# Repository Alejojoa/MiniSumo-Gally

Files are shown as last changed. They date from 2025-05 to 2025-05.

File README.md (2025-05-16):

# MiniSumo "Gally"                   
Mini sumo diseñado para competir en la LNR. 
Este repositorio contiene todas las piezas fabricables del Robot, y extras como soportes, versiones no finales del chasis, otros diseños de chasis, etc.

## ⚙️ Características 

- Tamaño: [10x10]
- Peso: [470g]
- Controlador: [Arduino Nano]
- Sensores:
  - Sensores de línea infrarrojos QRE-1113 x 2
  - Sensores JS40F x 4
- Motores: [Motores JSUMO CORE 400RPM]
- Batería: [Tattu 3S 450mAh]

# Pre Render del chasis final del robot.



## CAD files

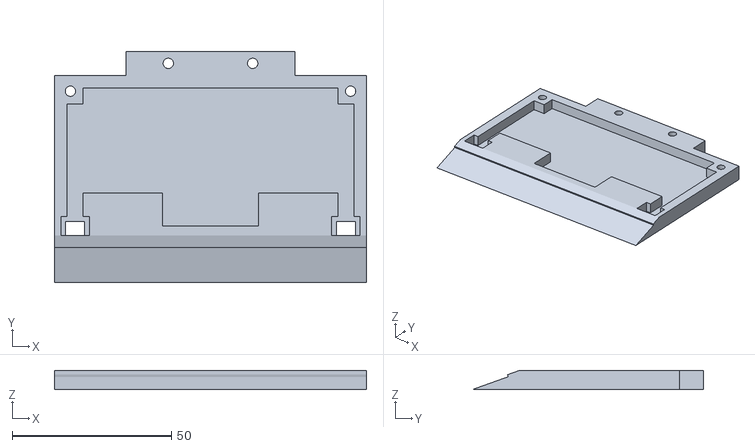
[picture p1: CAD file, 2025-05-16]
Hardware 3D (Chasis)/BasePLA.stl
98.0 x 72.6 x 6.00

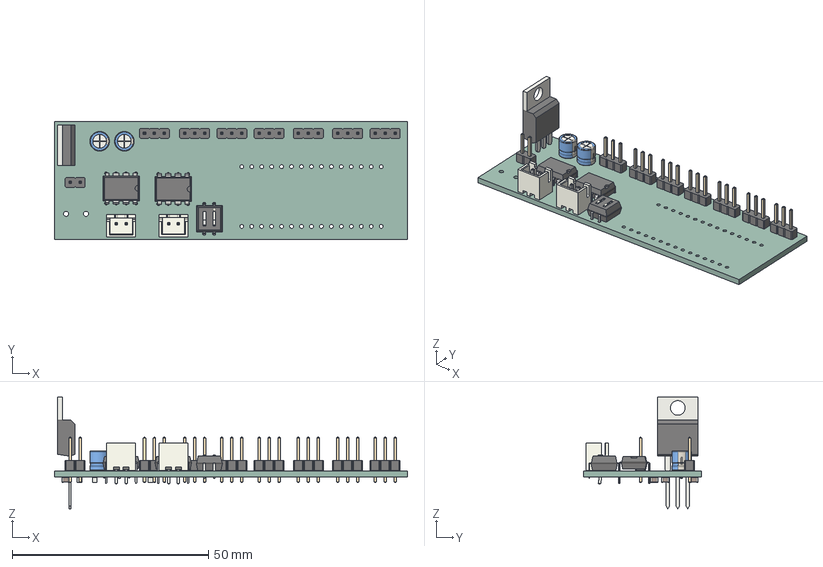
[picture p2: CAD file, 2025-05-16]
Hardware/UntestedBoard/Minisumo NANO.step
90.0 x 30.0 x 28.5 mm
SW_DIP_SPSTx02_Slide_67x664mm_W762mm_P254mm_LowProfile
PinHeader_1x02_P254mm_Vertical
JST_B2B_XH_A x 2
TO-220-3_Vertical
PinHeader_1x03_P254mm_Vertical x 7
CP_Radial_D50mm_P250mm x 2
DIP-8_W7.62mm x 2
C_0805_2012Metric x 4
Minisumo NANO_PCB

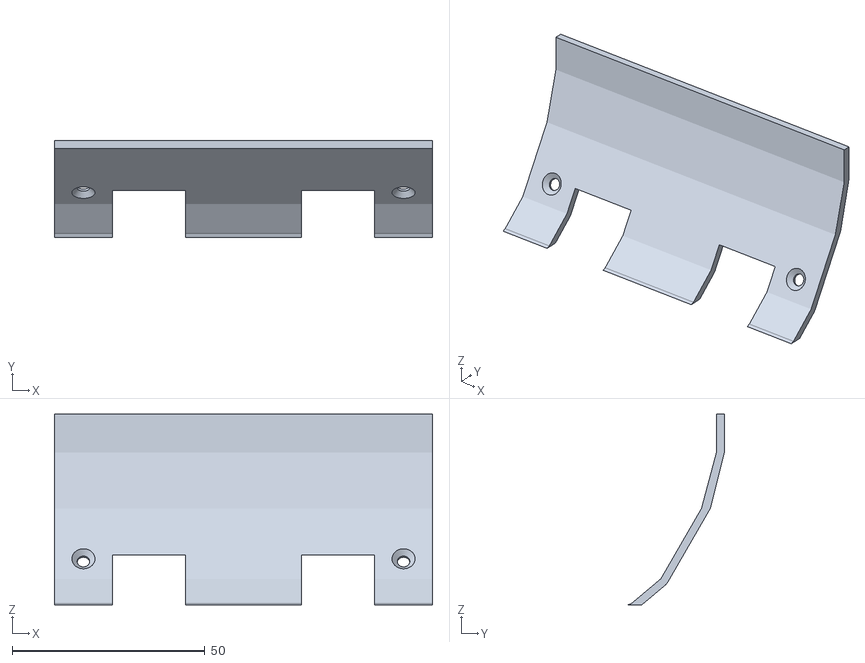
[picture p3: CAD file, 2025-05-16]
Hardware 3D (Chasis)/Frente.stl
98.0 x 25.1 x 49.5

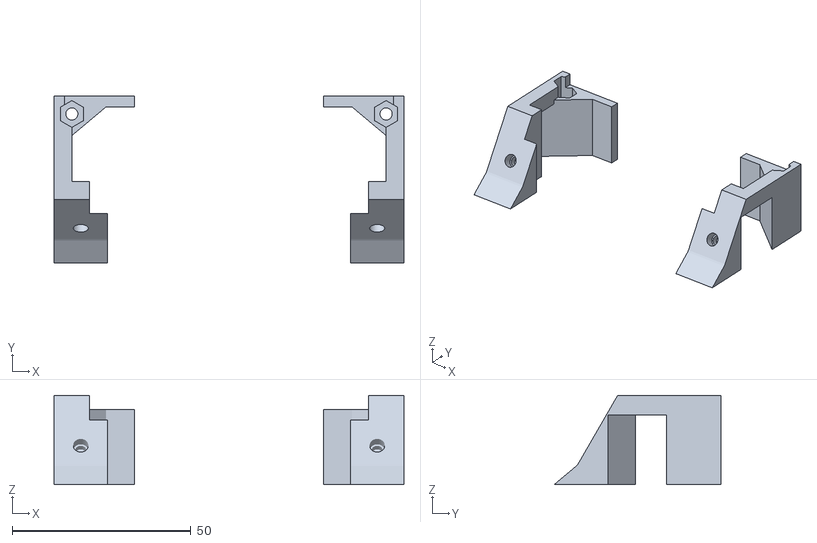
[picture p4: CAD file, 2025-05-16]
Hardware 3D (Chasis)/Laterales.stl
98.0 x 46.7 x 25.0

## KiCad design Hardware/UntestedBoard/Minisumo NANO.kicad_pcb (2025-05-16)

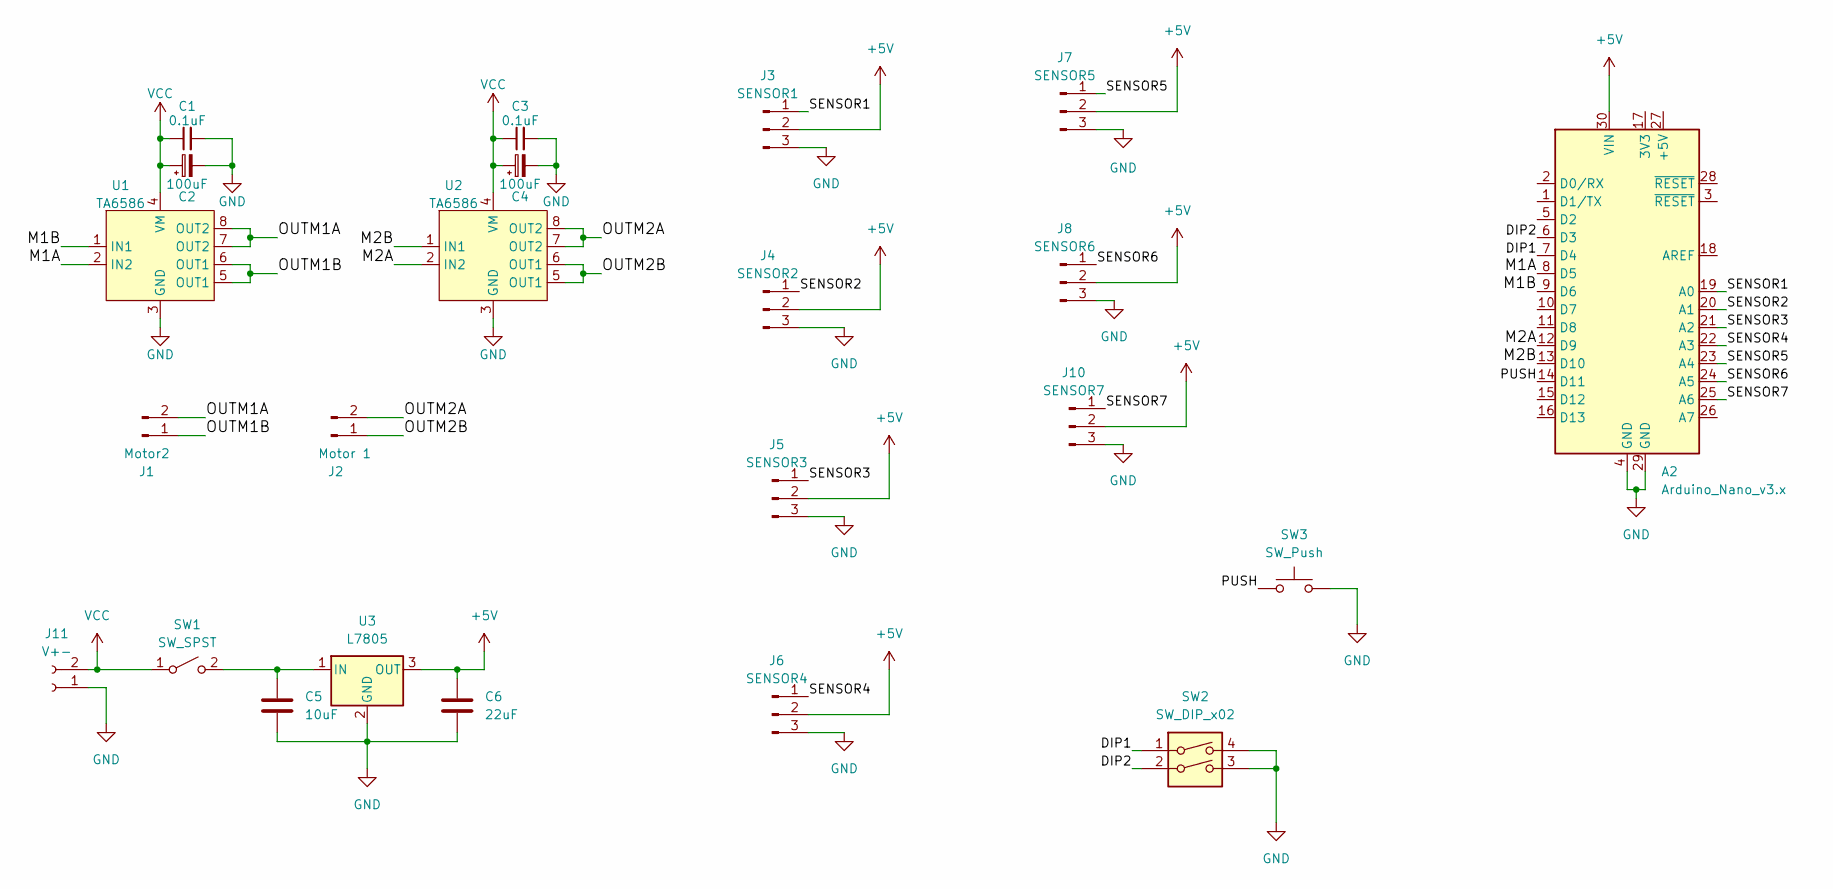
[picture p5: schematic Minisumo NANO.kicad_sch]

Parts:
A2: Arduino_Nano_v3.x; Arduino_Nano
C1, C3: 0.1uF; C_0805_2012Metric_Pad1.18x1.45mm_HandSolder
C2, C4: 100uF; CP_Radial_D5.0mm_P2.50mm
C5: 10uF; C_0805_2012Metric_Pad1.18x1.45mm_HandSolder
C6: 22uF; C_0805_2012Metric_Pad1.18x1.45mm_HandSolder
J1: Motor2; JST_XH_B2B-XH-A_1x02_P2.50mm_Vertical
J2: Motor 1; JST_XH_B2B-XH-A_1x02_P2.50mm_Vertical
J3: SENSOR1; PinHeader_1x03_P2.54mm_Vertical
J4: SENSOR2; PinHeader_1x03_P2.54mm_Vertical
J5: SENSOR3; PinHeader_1x03_P2.54mm_Vertical
J6: SENSOR4; PinHeader_1x03_P2.54mm_Vertical
J7: SENSOR5; PinHeader_1x03_P2.54mm_Vertical
J8: SENSOR6; PinHeader_1x03_P2.54mm_Vertical
J10: SENSOR7; PinHeader_1x03_P2.54mm_Vertical
J11: V+-; BORNERA2
SW1: SW_SPST; PinHeader_1x02_P2.54mm_Vertical
SW2: SW_DIP_x02; SW_DIP_SPSTx02_Slide_6.7x6.64mm_W7.62mm_P2.54mm_LowProfile
SW3: SW_Push; SW_PUSH_6mm_H5mm
U1, U2: TA6586; DIP-8_W7.62mm
U3: L7805; TO-220-3_Vertical

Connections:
+5V: A2.30 (VIN), C6.1, J3.2, J4.2, J5.2, J6.2, J7.2, J8.2, J10.2, U3.3 (OUT)
/DIP1: A2.7 (D4), SW2.1
/DIP2: A2.6 (D3), SW2.2
/M1A: A2.8 (D5), U1.2 (IN2)
/M1B: A2.9 (D6), U1.1 (IN1)
/M2A: A2.12 (D9), U2.2 (IN2)
/M2B: A2.13 (D10), U2.1 (IN1)
/OUTM1A: J1.2, U1.7 (OUT2), U1.8 (OUT2)
/OUTM1B: J1.1, U1.5 (OUT1), U1.6 (OUT1)
/OUTM2A: J2.2, U2.7 (OUT2), U2.8 (OUT2)
/OUTM2B: J2.1, U2.5 (OUT1), U2.6 (OUT1)
/PUSH: A2.14 (D11), SW3.1
/SENSOR1: A2.19 (A0), J3.1
/SENSOR2: A2.20 (A1), J4.1
/SENSOR3: A2.21 (A2), J5.1
/SENSOR4: A2.22 (A3), J6.1
/SENSOR5: A2.23 (A4), J7.1
/SENSOR6: A2.24 (A5), J8.1
/SENSOR7: A2.25 (A6), J10.1
GND: A2.4 (GND), A2.29 (GND), C1.2, C2.2, C3.2, C4.2, C5.2, C6.2, J3.3, J4.3, J5.3, J6.3, J7.3, J8.3, J10.3, J11.1, SW2.3, SW2.4, SW3.2, U1.3 (GND), U2.3 (GND), U3.2 (GND)
unnamed: C5.1, SW1.2 (B), U3.1 (IN)
VCC: C1.1, C2.1, C3.1, C4.1, J11.2, SW1.1 (A), U1.4 (VM), U2.4 (VM)

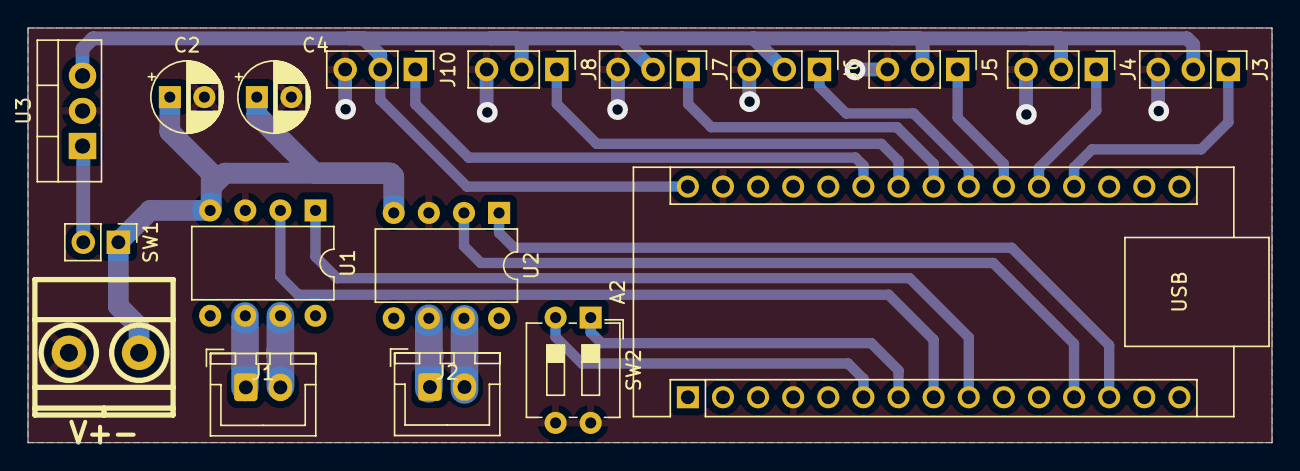
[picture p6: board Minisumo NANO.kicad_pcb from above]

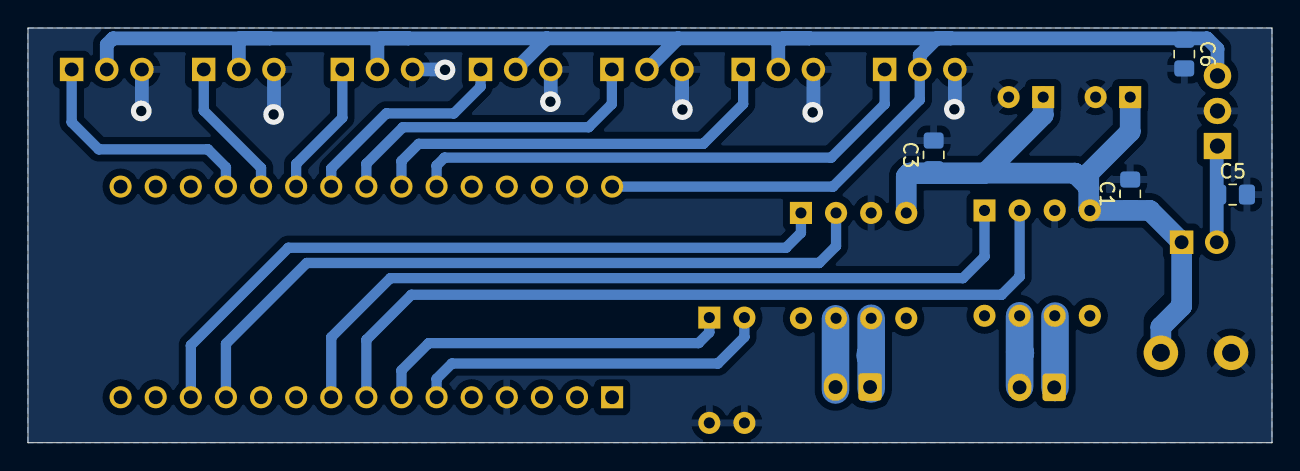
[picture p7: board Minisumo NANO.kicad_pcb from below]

Board: 2 copper layers, 90.0 x 30.0 mm, 22 parts (4 on the bottom side), 21 nets.

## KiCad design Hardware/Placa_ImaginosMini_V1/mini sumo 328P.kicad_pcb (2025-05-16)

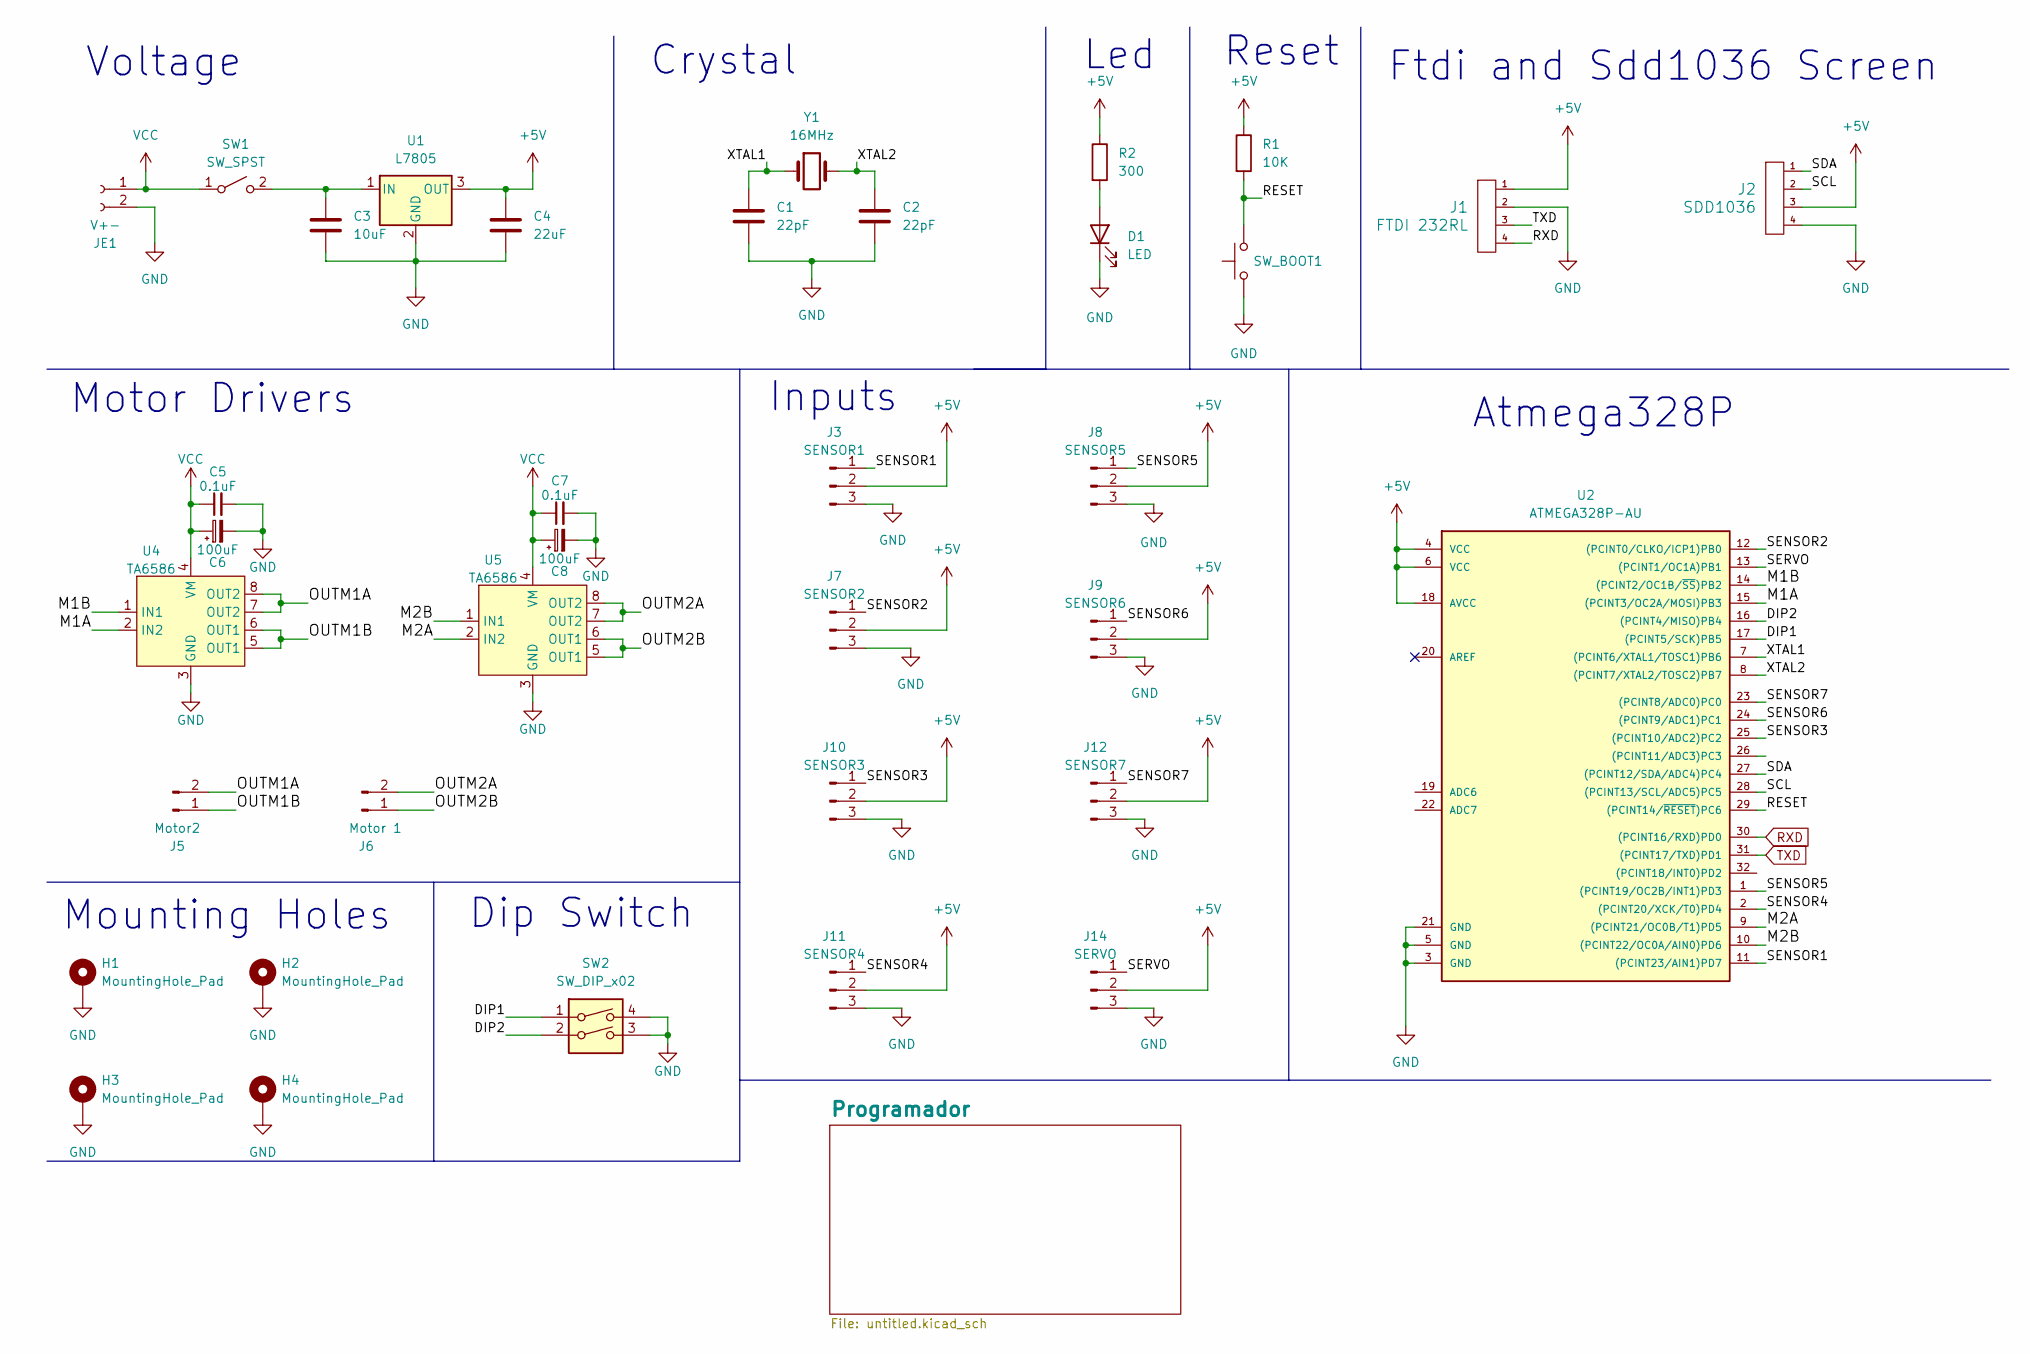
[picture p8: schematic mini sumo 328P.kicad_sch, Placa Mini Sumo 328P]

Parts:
C1, C2: 22pF; C_0805_2012Metric_Pad1.18x1.45mm_HandSolder
C3: 10uF; C_0805_2012Metric_Pad1.18x1.45mm_HandSolder
C4: 22uF; C_0805_2012Metric_Pad1.18x1.45mm_HandSolder
C5, C7: 0.1uF; C_0805_2012Metric_Pad1.18x1.45mm_HandSolder
C6, C8: 100uF; CP_EIA-3216-18_Kemet-A_Pad1.58x1.35mm_HandSolder
D1: LED; LED_0805_2012Metric_Pad1.15x1.40mm_HandSolder
H1, H2, H3, H4: MountingHole_Pad; MountingHole_3.2mm_M3_Pad_Via
J1: FTDI 232RL; PinHeader_1x04_P2.54mm_Vertical
J2: SDD1036; PinSocket_1x04_P2.54mm_Vertical
J3: SENSOR1; Smd pad vias x3
J5: Motor2; JST_XH_B2B-XH-A_1x02_P2.50mm_Vertical
J6: Motor 1; JST_XH_B2B-XH-A_1x02_P2.50mm_Vertical
J7: SENSOR2; Smd pad vias x3
J8: SENSOR5; Smd pad vias x3
J9: SENSOR6; Smd pad vias x3
J10: SENSOR3; Smd pad vias x3
J11: SENSOR4; Smd pad vias x3
J12: SENSOR7; Smd pad vias x3
J14: SERVO; PinSocket_1x03_P2.54mm_Vertical
JE1: V+-; BORNERA2_DUO
R1: 10K; R_0805_2012Metric_Pad1.20x1.40mm_HandSolder
R2: 300; R_0805_2012Metric_Pad1.20x1.40mm_HandSolder
SW1: SW_SPST; PinHeader_1x02_P2.54mm_Vertical
SW2: SW_DIP_x02; SW_DIP_SPSTx02_Slide_6.7x6.64mm_W7.62mm_P2.54mm_LowProfile
SW_BOOT1: SW_Push; Pulsador_SMD_2_BAJO
U1: L7805; TO-252-2
U2: ATMEGA328P-AU; TQFP-32_7x7mm_Pitch0.8mm
U4, U5: TA6586; DIP-8_W7.62mm
Y1: 16MHz; Crystal_HC49-4H_Vertical

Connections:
+5V: C4.1, J1.1, J2.3, J3.2, J7.2, J8.2, J9.2, J10.2, J11.2, J12.2, J14.2, R1.1, R2.1, U1.3 (OUT), U2.4 (VCC), U2.6 (VCC), U2.18 (AVCC); also elsewhere on the board
/DIP1: SW2.1, U2.17 ((PCINT5/SCK)PB5)
/DIP2: SW2.2, U2.16 ((PCINT4/MISO)PB4)
/M1A: U2.15 ((PCINT3/OC2A/MOSI)PB3), U4.2 (IN2)
/M1B: U2.14 ((PCINT2/OC1B/~SS)PB2), U4.1 (IN1)
/M2A: U2.9 ((PCINT21/OC0B/T1)PD5), U5.2 (IN2)
/M2B: U2.10 ((PCINT22/OC0A/AIN0)PD6), U5.1 (IN1)
/OUTM1A: J5.2, U4.7 (OUT2), U4.8 (OUT2)
/OUTM1B: J5.1, U4.5 (OUT1), U4.6 (OUT1)
/OUTM2A: J6.2, U5.7 (OUT2), U5.8 (OUT2)
/OUTM2B: J6.1, U5.5 (OUT1), U5.6 (OUT1)
/RESET: R1.2, SW_BOOT1.2, U2.29 ((PCINT14/~RESET)PC6)
/SCL: J2.2, U2.28 ((PCINT13/SCL/ADC5)PC5)
/SDA: J2.1, U2.27 ((PCINT12/SDA/ADC4)PC4)
/SENSOR1: J3.1, U2.11 ((PCINT23/AIN1)PD7)
/SENSOR2: J7.1, U2.12 ((PCINT0/CLKO/ICP1)PB0)
/SENSOR3: J10.1, U2.25 ((PCINT10/ADC2)PC2)
/SENSOR4: J11.1, U2.2 ((PCINT20/XCK/T0)PD4)
/SENSOR5: J8.1, U2.1 ((PCINT19/OC2B/INT1)PD3)
/SENSOR6: J9.1, U2.24 ((PCINT9/ADC1)PC1)
/SENSOR7: J12.1, U2.23 ((PCINT8/ADC0)PC0)
/SERVO: J14.1, U2.13 ((PCINT1/OC1A)PB1)
/XTAL1: C1.1, U2.7 ((PCINT6/XTAL1/TOSC1)PB6), Y1.1
/XTAL2: C2.1, U2.8 ((PCINT7/XTAL2/TOSC2)PB7), Y1.2
GND: C1.2, C2.2, C3.2, C4.2, C5.2, C6.2, C7.2, C8.2, D1.1 (K), H1.1, H2.1, H3.1, H4.1, J1.2, J2.4, J3.3, J7.3, J8.3, J9.3, J10.3, J11.3, J12.3, J14.3, JE1.2, SW2.3, SW2.4, SW_BOOT1.1, U1.2 (GND), U2.3 (GND), U2.5 (GND), U2.21 (GND), U4.3 (GND), U5.3 (GND); also elsewhere on the board
unnamed: D1.2 (A), R2.2
unnamed: C3.1, SW1.2 (B), U1.1 (IN)
RXD: J1.4, U2.30 ((PCINT16/RXD)PD0); also elsewhere on the board
TXD: J1.3, U2.31 ((PCINT17/TXD)PD1); also elsewhere on the board
VCC: C5.1, C6.1, C7.1, C8.1, JE1.1, SW1.1 (A), U4.4 (VM), U5.4 (VM)

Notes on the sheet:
Voltage
Crystal
Mounting Holes
Dip Switch
Ftdi and Sdd1036 Screen
Reset
Motor Drivers
Led
Inputs
Atmega328P

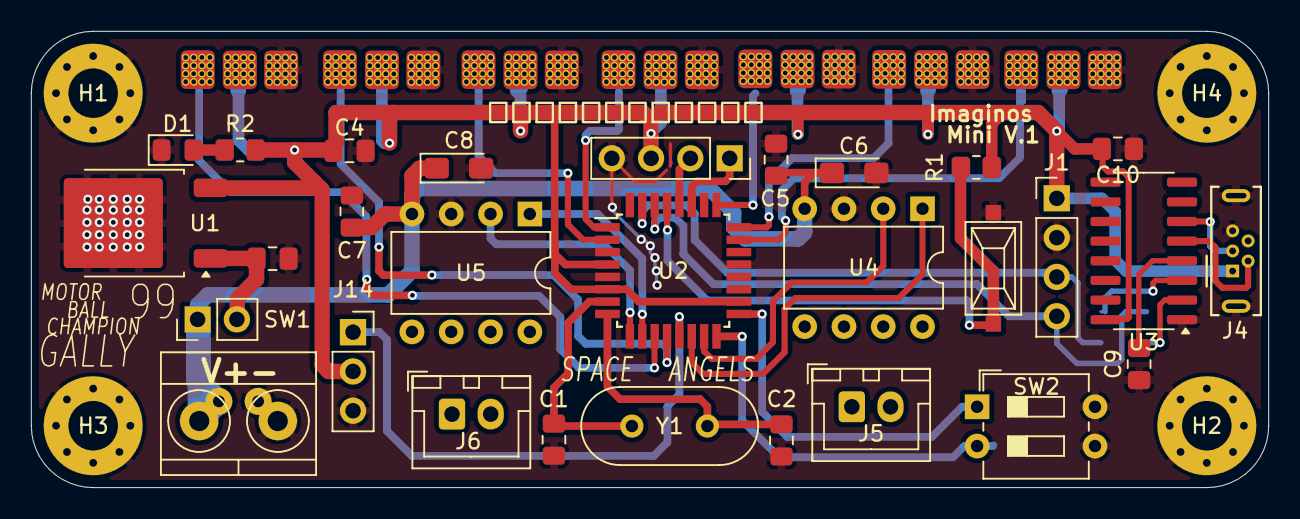
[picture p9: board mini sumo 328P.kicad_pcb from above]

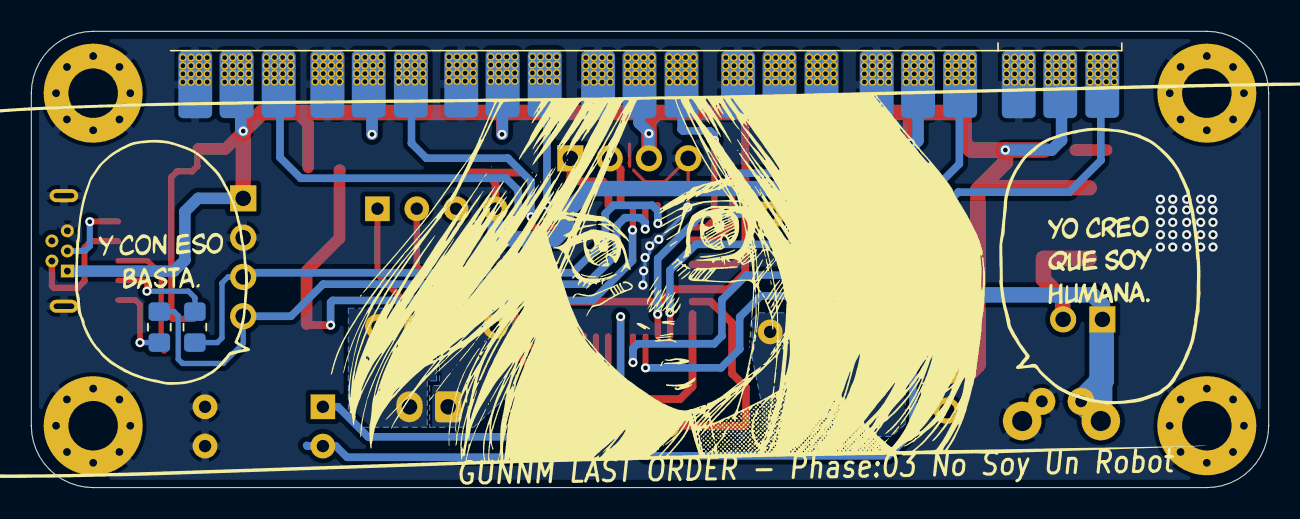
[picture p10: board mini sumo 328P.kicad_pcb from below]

Board: 2 copper layers, 80.0 x 29.5 mm, 42 parts (2 on the bottom side), 35 nets.

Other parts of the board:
C9, C10: C; C_0805_2012Metric_Pad1.18x1.45mm_HandSolder
J4: USB_B_Micro; USB_Micro-B_Wuerth_614105150721_Vertical
R3, R4: R; R_0805_2012Metric_Pad1.20x1.40mm_HandSolder
U3: CH340C; SOIC-16_3.9x9.9mm_P1.27mm

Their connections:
+5V: C10.2, J4.1 (VBUS), U3.16 (VCC); also elsewhere on the board
/Programador/D+: J4.3 (D+), U3.6 (UD-)
/Programador/D-: J4.2 (D-), U3.5 (UD+)
GND: C9.1, C10.1, J4.5 (GND), J4.6 (Shield), U3.1 (GND); also elsewhere on the board
unnamed: R4.2, U3.3 (RXD)
unnamed: R3.1, U3.2 (TXD)
unnamed: C9.2, U3.4 (V3)
RXD: R3.2; also elsewhere on the board
TXD: R4.1; also elsewhere on the board
